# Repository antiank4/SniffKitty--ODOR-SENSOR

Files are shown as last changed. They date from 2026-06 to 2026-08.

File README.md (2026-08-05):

# SniffKitty

An ESP32-S3 multisensor system for monitoring odor changes around pet spaces. SniffKitty combines ammonia and air-quality sensing, temperature and humidity measurements, camera-based presence detection, local data logging, and a live web dashboard inside a custom 3D-printed enclosure.

> SniffKitty reports relative changes from a startup baseline. It is an engineering prototype, not a calibrated safety, health, or veterinary instrument.

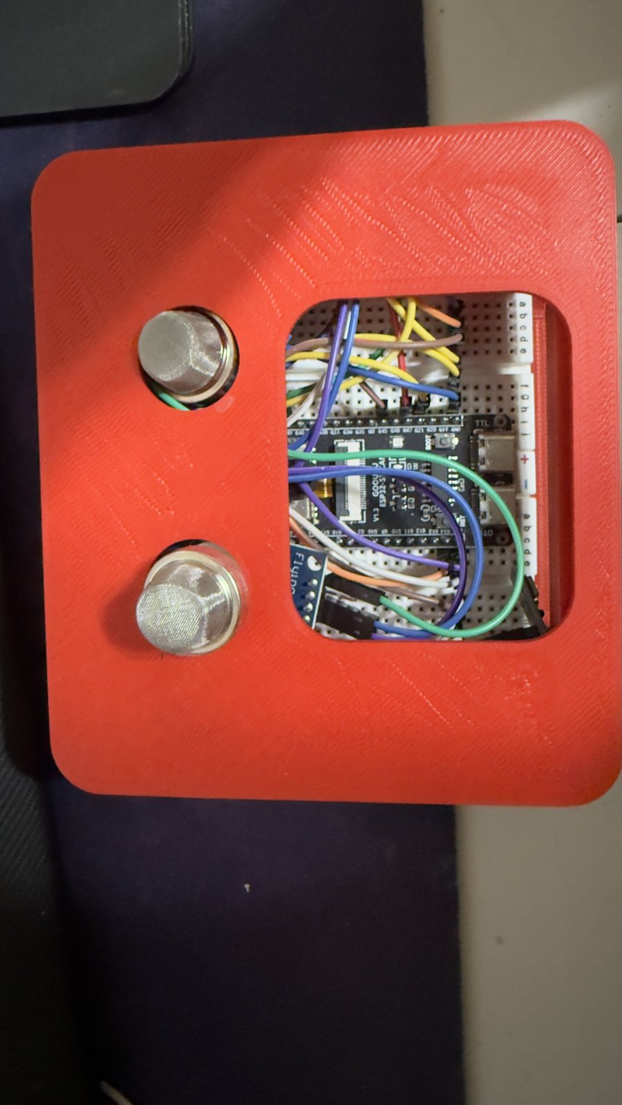
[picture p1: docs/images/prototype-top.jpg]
SniffKitty assembled prototype


## What it does

- Samples MQ137 and MQ135 analog gas sensors and compares readings with a clean-air startup baseline.
- Uses an AHT10 to record temperature and relative humidity.
- Detects pet presence from camera frame changes without sending images to a cloud service.
- Serves a live dashboard and camera stream from the ESP32-S3.
- Records timestamped sensor data to microSD and automatically retries after card failures.
- Captures a local photo when a new presence event begins.
- Provides an offline access-point mode when the configured Wi-Fi network is unavailable.
- Indicates odor-change severity through an addressable status LED.
- Exports serial readings to CSV through the included Python utility.

## System overview

```text
MQ137 ─┐
MQ135 ─┼─> ESP32-S3 ──> Web dashboard / camera stream
AHT10 ─┤       │
Camera ┘       ├──────> microSD CSV + event photos
               ├──────> status LED
               └──────> USB serial CSV capture
```

ESP32-S3 wiring diagram

The full pin table, electrical notes, and signal descriptions are in [Hardware documentation](docs/HARDWARE.md).

## Hardware variants

Each branch is a self-contained, working hardware configuration from a different stage of the prototype. The `demo` branch is the most complete system and is the version documented throughout the rest of this README.

| Branch | Hardware configuration | Distinguishing features |
| --- | --- | --- |
| [`main`](https://github.com/antiank4/SniffKitty--ODOR-SENSOR/tree/main) | MQ135, PIR sensor, AHT10, camera, microSD, status LED | Stable PIR-triggered MQ135 build with live video and offline logging |
| [`feature`](https://github.com/antiank4/SniffKitty--ODOR-SENSOR/tree/feature) | MQ135, PIR sensor, AHT10, camera | Earlier v0.2 dashboard and chart build with PIR-triggered recording |
| [`mq137-version`](https://github.com/antiank4/SniffKitty--ODOR-SENSOR/tree/mq137-version) | MQ137, PIR sensor, AHT10, camera, microSD, status LED | Replaces MQ135 with the ammonia-sensitive MQ137 while retaining PIR presence detection |
| [`camera-detected-movement-version`](https://github.com/antiank4/SniffKitty--ODOR-SENSOR/tree/camera-detected-movement-version) | MQ137, AHT10, camera, microSD, status LED | Replaces the PIR sensor with camera-frame change detection |
| [`camera+mq135+mq137-version`](https://github.com/antiank4/SniffKitty--ODOR-SENSOR/tree/camera%2Bmq135%2Bmq137-version) | MQ135, MQ137, AHT10, camera, microSD, status LED | Adds dual gas sensing to the camera-presence design |
| [`time`](https://github.com/antiank4/SniffKitty--ODOR-SENSOR/tree/time) | MQ135, MQ137, AHT10, camera, microSD, status LED | Adds synchronized timestamps and a revised dashboard to the dual-sensor build |
| [`demo`](https://github.com/antiank4/SniffKitty--ODOR-SENSOR/tree/demo) | MQ135, MQ137, AHT10, camera, microSD, status LED | Final Demo Day build with tuned filtering, event photos, resilient storage, local access point, and enterprise Wi-Fi support |

## Prototype and enclosure

| Top | Front | Ventilated side |
| --- | --- | --- |
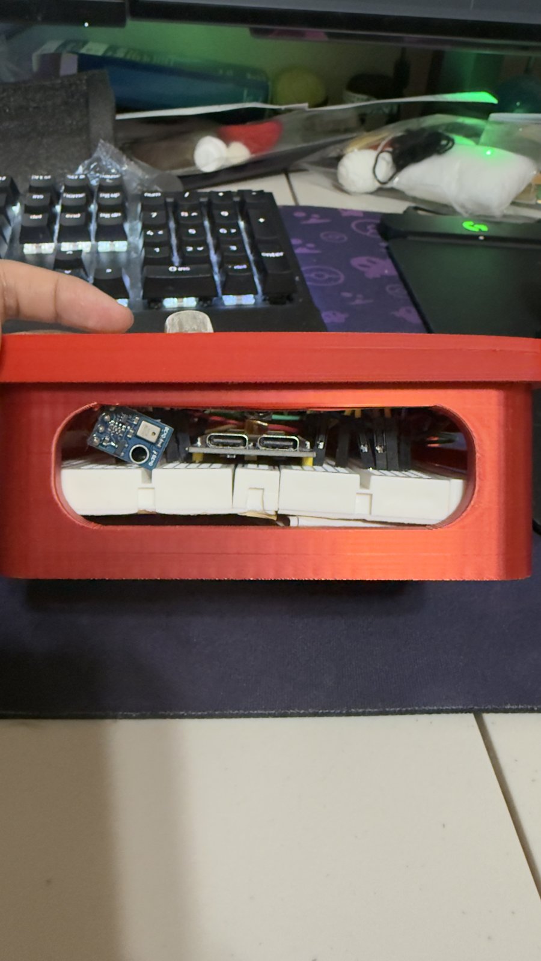
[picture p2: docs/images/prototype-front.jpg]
Front view showing the controller ports and sensor board
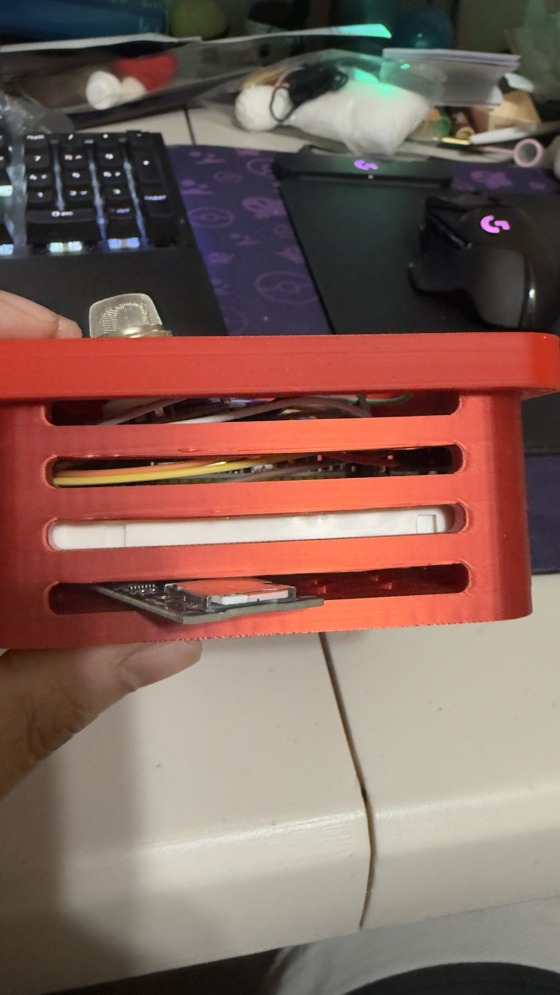
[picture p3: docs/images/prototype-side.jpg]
Side view showing ventilation slots and camera
| Top view showing two gas sensors and the controller |  |  |

The enclosure was designed for 3D printing with openings for the two gas sensors, camera, controller ports, and passive airflow. Source SolidWorks and 3MF files are available in [`hardware/cad`](hardware/cad/).

CAD mesh overview

## Hardware

- ESP32-S3 DevKitC-1 with 16 MB flash and PSRAM
- Camera module using an 8-bit DVP interface
- MQ137 ammonia-sensitive gas sensor module
- MQ135 air-quality gas sensor module
- AHT10 temperature and humidity sensor
- MicroSD card module
- Addressable status LED
- Breadboard, jumper wiring, and external power as required
- Custom 3D-printed enclosure

## Firmware setup

### 1. Install the toolchain

Install [Visual Studio Code](https://code.visualstudio.com/) and the PlatformIO extension, or install PlatformIO Core.

### 2. Configure Wi-Fi

Copy the example credentials file:

```text
include/wifi_credentials.example.h
```

to:

```text
include/wifi_credentials.h
```

Then replace the placeholder values. The real credentials file is excluded by `.gitignore` and must never be committed.

For a normal WPA/WPA2 network, provide `WIFI_SSID` and `WIFI_PASSWORD`. For eduroam or another WPA Enterprise network, leave `WIFI_PASSWORD` empty and provide the enterprise username and password.

### 3. Build and upload

From PlatformIO:

```bash
pio run
pio run --target upload
pio device monitor --baud 115200
```

The configured environment is `esp32s3cam`. On startup, the firmware initializes storage and the camera, connects Wi-Fi, calibrates both gas-sensor baselines for 30 seconds, and then begins monitoring.

### 4. Open the dashboard

The serial monitor prints the station IP address after a successful Wi-Fi connection. If station connection fails, connect to the local `SniffKitty-Demo` access point and use the IP address printed over serial.

## Serial CSV capture

Install PySerial:

```bash
python -m pip install pyserial
```

Update `PORT` in `save_gas_csv.py` for the connected board, then run:

```bash
python save_gas_csv.py
```

The current firmware records timestamps, presence state, raw and converted gas-sensor readings, relative change, status labels, temperature, humidity, and environmental deltas. The repository's `mq135_data.csv` is retained as an early prototype dataset and uses an older schema.

## My contribution

This was a three-person team project. My responsibilities included:

- All embedded firmware and supporting Python code
- Sensor acquisition, baseline calibration, filtering, and event-state logic
- Camera-based presence detection and local web dashboard
- Wi-Fi, offline access-point mode, NTP synchronization, and microSD logging
- Hardware integration, wiring, debugging, and physical prototype assembly
- 3D enclosure design, iteration, and printing

## Repository layout

```text
include/                 Firmware headers and embedded dashboard UI
src/                     ESP32-S3 firmware modules
docs/                    Photos, wiring diagram, and hardware documentation
hardware/cad/            SolidWorks and printable 3MF enclosure files
scripts/                 Documentation-generation utilities
save_gas_csv.py          Optional USB serial data logger
platformio.ini           Board and dependency configuration
```

## Known limitations and next steps

- Gas readings represent relative change, not calibrated gas concentration in ppm.
- Camera presence detection depends on lighting, placement, and threshold tuning.
- The prototype uses breadboard wiring; a future revision should use a custom PCB and protected power inputs.
- The serial capture utility currently requires its port to be edited manually.
- Automated firmware builds and hardware-independent tests have not yet been added.

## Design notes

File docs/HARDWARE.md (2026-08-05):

# Hardware and wiring

This document records the signal assignments implemented in `include/config.h`. It is intended to help explain and reproduce the prototype; verify the voltage requirements and pinout of each exact breakout board before powering new hardware.

SniffKitty wiring diagram

## Signal connections

| Module | Module signal | ESP32-S3 pin | Firmware constant |
| --- | --- | ---: | --- |
| MQ137 | Analog output | GPIO 1 | `MQ137_PIN` |
| MQ135 | Analog output | GPIO 2 | `MQ135_PIN` |
| AHT10 | SDA | GPIO 14 | `AHT_SDA` |
| AHT10 | SCL | GPIO 21 | `AHT_SCL` |
| microSD | SCK | GPIO 42 | `SD_SCK_PIN` |
| microSD | MISO | GPIO 41 | `SD_MISO_PIN` |
| microSD | MOSI | GPIO 47 | `SD_MOSI_PIN` |
| microSD | CS | GPIO 45 | `SD_CS_PIN` |
| Addressable LED | Data input | GPIO 48 | `STATUS_LED_PIN` |
| Camera | XCLK | GPIO 15 | `XCLK_GPIO_NUM` |
| Camera | SIOD | GPIO 4 | `SIOD_GPIO_NUM` |
| Camera | SIOC | GPIO 5 | `SIOC_GPIO_NUM` |
| Camera | Y2–Y9 | GPIO 11, 9, 8, 10, 12, 18, 17, 16 | `Y2_GPIO_NUM`–`Y9_GPIO_NUM` |
| Camera | VSYNC | GPIO 6 | `VSYNC_GPIO_NUM` |
| Camera | HREF | GPIO 7 | `HREF_GPIO_NUM` |
| Camera | PCLK | GPIO 13 | `PCLK_GPIO_NUM` |

All modules must share a common ground.

## Electrical notes

- ESP32-S3 GPIO and ADC inputs are not 5 V tolerant. Ensure each MQ module's analog output cannot exceed 3.3 V; use a voltage divider or signal-conditioning circuit if required.
- MQ sensor heater circuits commonly require 5 V and draw substantially more current than logic-only sensors. Size the power supply for both heater modules and avoid sourcing their heater current from a GPIO pin.
- Confirm whether the specific microSD breakout includes regulation and level shifting. A bare microSD card uses 3.3 V signaling.
- Keep analog signal wiring short and route it away from camera clocks, SD traffic, and switching power wiring where practical.
- The current firmware uses relative baseline changes. Meaningful ppm estimates would require sensor-specific calibration with known gas concentrations, load resistance documentation, warm-up characterization, and environmental compensation.

## Mechanical files

| File | Purpose |
| --- | --- |
| [`enclosure-body.3mf`](../hardware/cad/enclosure-body.3mf) | Printable enclosure body |
| [`lid-v1.3mf`](../hardware/cad/lid-v1.3mf) | Original printable lid |
| [`lid-v2.3mf`](../hardware/cad/lid-v2.3mf) | Revised printable lid |
| [`enclosure-part-1.SLDPRT`](../hardware/cad/enclosure-part-1.SLDPRT) | SolidWorks source part |
| [`enclosure-part-2.SLDPRT`](../hardware/cad/enclosure-part-2.SLDPRT) | SolidWorks source part |

Enclosure CAD overview

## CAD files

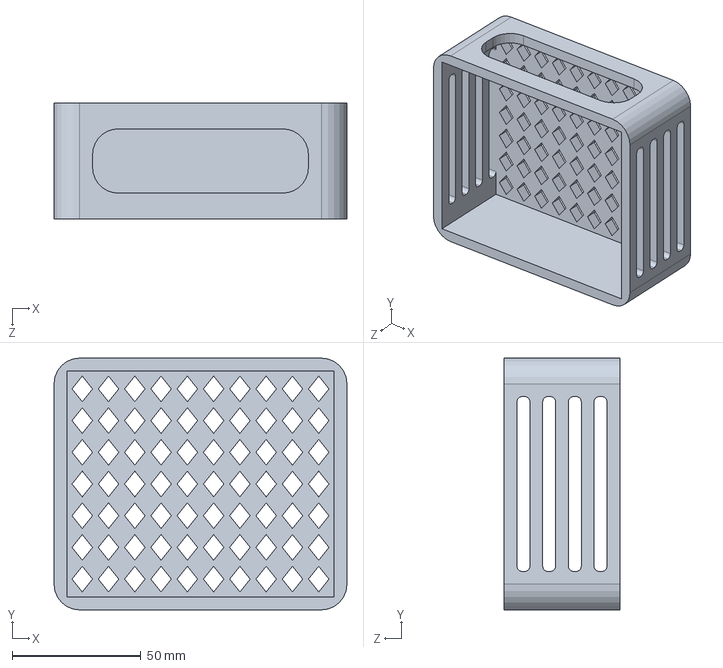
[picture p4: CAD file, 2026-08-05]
hardware/cad/enclosure-part-1.SLDPRT
114.0 x 98.0 x 45.0 mm

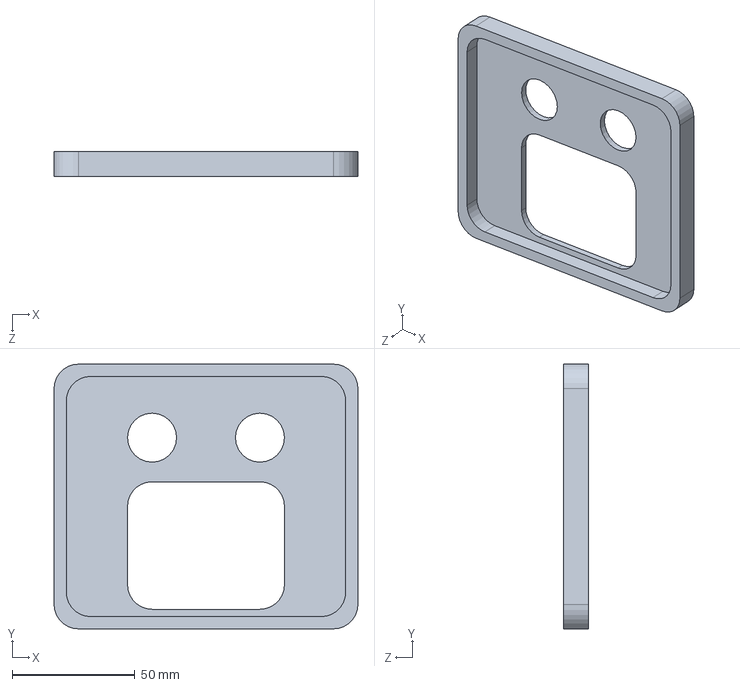
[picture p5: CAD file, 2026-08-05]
hardware/cad/enclosure-part-2.SLDPRT
124.0 x 108.0 x 10.0 mm

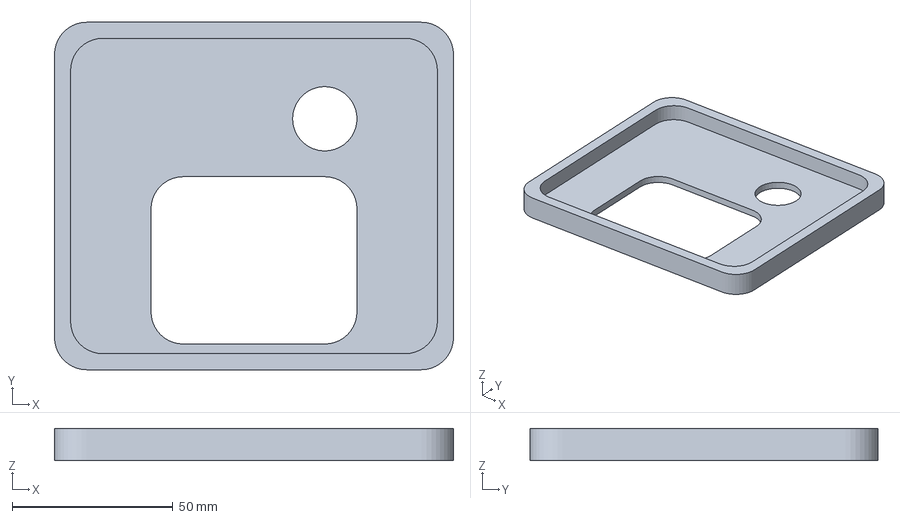
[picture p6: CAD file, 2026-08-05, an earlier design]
hardware/cad/lid-v1.3mf
124.0 x 108.0 x 10.0 mm

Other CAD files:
hardware/cad/enclosure-body.3mf
hardware/cad/lid-v2.3mf

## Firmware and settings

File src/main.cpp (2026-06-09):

#include <Arduino.h>

#include "sensors.h"
#include "camera_server.h"
#include "storage.h"
#include "status_led.h"

void setup() {
  Serial.begin(115200);
  delay(2000);

  initSensors();

  initStatusLed();

  initStorage();

  initCamera();

  connectWiFi();

  startCameraServer();

  captureCameraBaselineAfterDelay();

  calibrateBaseline();

  Serial.println("Waiting for camera presence...");
  Serial.println("CSV,timestamp,time_ms,recording,present,mq137_raw,mq137_voltage,ammonia_change_percent,ammonia_status,mq135_raw,mq135_voltage,air_change_percent,air_status,temp_C,hum_percent,delta_temp,delta_hum");
}

void loop() {
  updateStorage();

  updateSensors();

  printSensorStatus();

  printCSVIfRecording();
}

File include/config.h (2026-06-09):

#ifndef CONFIG_H
#define CONFIG_H

#include <Arduino.h>

extern const char* ssid;
extern const char* password;
extern const char* enterpriseUsername;
extern const char* enterprisePassword;

const char* const DEMO_AP_SSID = "SniffKitty-Demo";
const char* const DEMO_AP_PASSWORD = "12345678";
const unsigned long WIFI_CONNECT_TIMEOUT_MS = 25000;

const int MQ137_PIN = 1;
const int MQ135_PIN = 2;
const int AHT_SDA = 14;
const int AHT_SCL = 21;

const int SD_SCK_PIN = 42;
const int SD_MISO_PIN = 41;
const int SD_MOSI_PIN = 47;
const int SD_CS_PIN = 45;
const uint32_t SD_SPI_FREQ = 400000;
const char* const SD_LOG_PATH = "/gas_data.csv";
const bool SAVE_PRESENCE_PHOTO_ENABLED = true;
const unsigned long SD_RETRY_INTERVAL_MS = 5000;
const unsigned long CLOCK_SYNC_TIMEOUT_MS = 20000;
const unsigned long CLOCK_RETRY_INTERVAL_MS = 30000;

const bool STATUS_LED_ENABLED = true;
const int STATUS_LED_PIN = 48;
const uint8_t STATUS_LED_BRIGHTNESS = 24;
const float LED_SLIGHT_CHANGE_PERCENT = 10.0;
const float LED_MEDIUM_CHANGE_PERCENT = 30.0;
const float LED_STRONG_CHANGE_PERCENT = 80.0;

const float MQ137_CHANGE_MULTIPLIER = 2.0;
const int SAMPLE_COUNT = 2;
const int DELAY_BETWEEN_SAMPLES = 2;
const int MQ135_SAMPLE_COUNT = 12;
const float MQ135_IDLE_FILTER_ALPHA = 0.18;
const float MQ135_ACTIVE_FILTER_ALPHA = 0.70;
const int MQ135_IDLE_RAW_DEADBAND = 8;
const int MQ135_ACTIVE_RAW_DEADBAND = 1;
const float MQ135_IDLE_CHANGE_MULTIPLIER = 1.0;
const float MQ135_ACTIVE_CHANGE_MULTIPLIER = 1.5;
const float MQ135_IDLE_NOISE_FLOOR_PERCENT = 5.0;
const unsigned long MQ135_POST_CLOSE_BOOST_MS = 3000;

const unsigned long PRESENCE_IGNORE_AFTER_TRIGGER = 5000;
const unsigned long PRESENCE_RECORD_AFTER_EMPTY_MS = 20000;

const unsigned long CAMERA_BASELINE_DELAY_MS = 10000;
const unsigned long CAMERA_CHECK_INTERVAL_MS = 1000;
const int CAMERA_COMPARE_SAMPLE_STEP = 8;
const int CAMERA_PIXEL_DIFF_THRESHOLD = 35;
const float CAMERA_PRESENT_CHANGE_PERCENT = 7.0;
const float CAMERA_EMPTY_CHANGE_PERCENT = 7.0;
const int CAMERA_PRESENT_SAMPLE_MIN = 2;
const int CAMERA_EMPTY_SAMPLE_MIN = 2;

#define PWDN_GPIO_NUM     -1
#define RESET_GPIO_NUM    -1
#define XCLK_GPIO_NUM     15
#define SIOD_GPIO_NUM     4
#define SIOC_GPIO_NUM     5

#define Y9_GPIO_NUM       16
#define Y8_GPIO_NUM       17
#define Y7_GPIO_NUM       18
#define Y6_GPIO_NUM       12
#define Y5_GPIO_NUM       10
#define Y4_GPIO_NUM       8
#define Y3_GPIO_NUM       9
#define Y2_GPIO_NUM       11

#define VSYNC_GPIO_NUM    6
#define HREF_GPIO_NUM     7
#define PCLK_GPIO_NUM     13

#endif

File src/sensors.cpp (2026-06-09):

#include "sensors.h"
#include "camera_server.h"
#include "config.h"
#include "storage.h"
#include "status_led.h"
#include <math.h>
#include <Wire.h>

int baseline = 0;
int mq135Baseline = 0;

bool recording = false;
unsigned long lastTriggerTime = 0;
unsigned long recordingStartTime = 0;
bool postRecording = false;
unsigned long postRecordingEndTime = 0;

Adafruit_AHTX0 aht;
bool ahtReady = false;

float baseTemp = 0;
float baseHum = 0;

float currentTempC = 0;
float currentHum = 0;
float currentDeltaTemp = 0;
float currentDeltaHum = 0;

int currentMQ137Raw = 0;
float currentVoltage = 0;
float currentChangePercent = 0;
String currentStatus = "Waiting";
int currentMQ135Raw = 0;
float currentMQ135Voltage = 0;
float currentMQ135ChangePercent = 0;
String currentMQ135Status = "Waiting";
bool currentPresenceState = false;
static bool pendingPresencePhoto = false;

static int readGasAverage(int pin, int sampleCount) {
  long sum = 0;
  int minVal = 4095;
  int maxVal = 0;

  for (int i = 0; i < sampleCount; i++) {
    int val = analogRead(pin);
    sum += val;
    minVal = min(minVal, val);
    maxVal = max(maxVal, val);
    delay(DELAY_BETWEEN_SAMPLES);
  }

  if (sampleCount > 2) {
    sum -= minVal;
    sum -= maxVal;
    return sum / (sampleCount - 2);
  }

  return sum / sampleCount;
}

int readMQ137Average() {
  return readGasAverage(MQ137_PIN, SAMPLE_COUNT);
}

int readMQ135Average() {
  return readGasAverage(MQ135_PIN, MQ135_SAMPLE_COUNT);
}

void calibrateBaseline() {
  Serial.println("Calibrating MQ137 + MQ135... keep air clean");

  unsigned long calibrationTime = 30000; // 10秒，可以改成 15000 或 30000
  unsigned long startTime = millis();

  long mq137Sum = 0;
  long mq135Sum = 0;
  int count = 0;

  while (millis() - startTime < calibrationTime) {
    mq137Sum += readMQ137Average();
    mq135Sum += readMQ135Average();
    count++;

    Serial.print(".");
    delay(50);
  }

  if (count > 0) {
    baseline = mq137Sum / count;
    mq135Baseline = mq135Sum / count;
  }

  Serial.println();
  Serial.print("MQ137 Baseline = ");
  Serial.println(baseline);
  Serial.print("MQ135 Baseline = ");
  Serial.println(mq135Baseline);
}

void updateStatusFromMQ137() {
  if (currentChangePercent < 10) {
    currentStatus = "Normal";
  } else if (currentChangePercent < 30) {
    currentStatus = "Slight Change";
  } else if (currentChangePercent < 80) {
    currentStatus = "Medium Ammonia";
  } else {
    currentStatus = "Strong Ammonia!";
  }
}

void updateStatusFromMQ135() {
  if (currentMQ135ChangePercent < 10) {
    currentMQ135Status = "Normal";
  } else if (currentMQ135ChangePercent < 30) {
    currentMQ135Status = "Slight Change";
  } else if (currentMQ135ChangePercent < 80) {
    currentMQ135Status = "Medium Air Change";
  } else {
    currentMQ135Status = "Strong Air Change!";
  }
}

void initSensors() {
  analogReadResolution(12);
  analogSetPinAttenuation(MQ137_PIN, ADC_11db);
  analogSetPinAttenuation(MQ135_PIN, ADC_11db);

  Wire.begin(AHT_SDA, AHT_SCL);

  Serial.println("MQ137 + MQ135 + camera presence + AHT10 + Web Dashboard start...");

  if (!aht.begin()) {
    Serial.println("AHT10 not found!");
    ahtReady = false;
  } else {
    Serial.println("AHT10 found!");
    ahtReady = true;
  }
}

void updateSensors() {
  bool previousPresenceState = currentPresenceState;
  currentPresenceState = updateCameraPresence();

  if (currentPresenceState) {
    if (!previousPresenceState) {
      pendingPresencePhoto = true;
    }

    if (postRecording) {
      postRecording = false;
      Serial.println("Camera present: cancel post-empty recording");
    }

    if (!recording) {
      recording = true;
      lastTriggerTime = millis();
      recordingStartTime = millis();

      Serial.println("Camera present: START recording");
      Serial.print("Ignoring first ");
      Serial.print(PRESENCE_IGNORE_AFTER_TRIGGER / 1000);
      Serial.println(" seconds of data after present trigger");

      if (ahtReady) {
        sensors_event_t humidity, temp;
        aht.getEvent(&humidity, &temp);

        baseTemp = temp.temperature;
        baseHum = humidity.relative_humidity;
      }
    }
  } else if (previousPresenceState && recording && !postRecording) {
    lastTriggerTime = millis();

    if (millis() - recordingStartTime >= PRESENCE_IGNORE_AFTER_TRIGGER) {
      postRecording = true;
      postRecordingEndTime = millis() + PRESENCE_RECORD_AFTER_EMPTY_MS;
      Serial.print("Camera empty: post recording for ");
      Serial.print(PRESENCE_RECORD_AFTER_EMPTY_MS / 1000);
      Serial.println(" seconds");
    } else {
      recording = false;
      Serial.println("Camera empty: STOP recording short trigger ignored");
    }
  }

  if (postRecording && millis() >= postRecordingEndTime) {
    postRecording = false;
    recording = false;
    Serial.println("Post recording complete: STOP recording");
  }

  if (ahtReady) {
    sensors_event_t humidity, temp;
    aht.getEvent(&humidity, &temp);

    currentTempC = temp.temperature;
    currentHum = humidity.relative_humidity;

    if (recording) {
      currentDeltaTemp = currentTempC - baseTemp;
      currentDeltaHum = currentHum - baseHum;
    } else {
      currentDeltaTemp = 0;
      currentDeltaHum = 0;
    }
  }

  currentMQ137Raw = readMQ137Average();
  currentVoltage = currentMQ137Raw * (3.3 / 4095.0);
  bool mq135PostCloseBoost = false;
  if (postRecording && postRecordingEndTime > millis()) {
    unsigned long postCloseElapsedMs = PRESENCE_RECORD_AFTER_EMPTY_MS - (postRecordingEndTime - millis());
    mq135PostCloseBoost = postCloseElapsedMs < MQ135_POST_CLOSE_BOOST_MS;
  }
  bool mq135ActiveMode = currentPresenceState || (recording && !postRecording) || mq135PostCloseBoost;
  float mq135FilterAlpha = mq135ActiveMode ? MQ135_ACTIVE_FILTER_ALPHA : MQ135_IDLE_FILTER_ALPHA;
  int mq135RawDeadband = mq135ActiveMode ? MQ135_ACTIVE_RAW_DEADBAND : MQ135_IDLE_RAW_DEADBAND;
  float mq135ChangeMultiplier = mq135ActiveMode ? MQ135_ACTIVE_CHANGE_MULTIPLIER : MQ135_IDLE_CHANGE_MULTIPLIER;

  int mq135RawSample = readMQ135Average();
  if (currentMQ135Raw == 0) {
    currentMQ135Raw = mq135RawSample;
  } else if (abs(mq135RawSample - currentMQ135Raw) > mq135RawDeadband) {
    currentMQ135Raw = round((mq135FilterAlpha * mq135RawSample) + ((1.0 - mq135FilterAlpha) * currentMQ135Raw));
  }
  currentMQ135Voltage = currentMQ135Raw * (3.3 / 4095.0);

  if (baseline > 0) {
    currentChangePercent = ((float)(currentMQ137Raw - baseline) / baseline) * 100 * MQ137_CHANGE_MULTIPLIER;
  } else {
    currentChangePercent = 0;
  }

  if (mq135Baseline > 0) {
    float mq135DeltaPercent = ((float)(currentMQ135Raw - mq135Baseline) / mq135Baseline) * 100;
    currentMQ135ChangePercent = fabs(mq135DeltaPercent) * mq135ChangeMultiplier;
    if (!mq135ActiveMode && currentMQ135ChangePercent < MQ135_IDLE_NOISE_FLOOR_PERCENT) {
      currentMQ135ChangePercent = 0;
    }
  } else {
    currentMQ135ChangePercent = 0;
  }
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

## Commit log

2026-04-29 Add data save
    [mq135_data.csv]
2026-05-26 change pir sensor to camera
2026-05-27 update the light logic and camera logic
2026-08-05 Document hardware variants and enclosure design
    [enclosure-body.3mf, enclosure-part-1.SLDPRT, enclosure-part-2.SLDPRT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]
